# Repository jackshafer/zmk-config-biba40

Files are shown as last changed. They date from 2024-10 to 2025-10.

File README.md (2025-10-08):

# Biba40
## The BIBA40 is a compact, split, wireless keyboard powered by ZMK firmware and two microcontrollers.

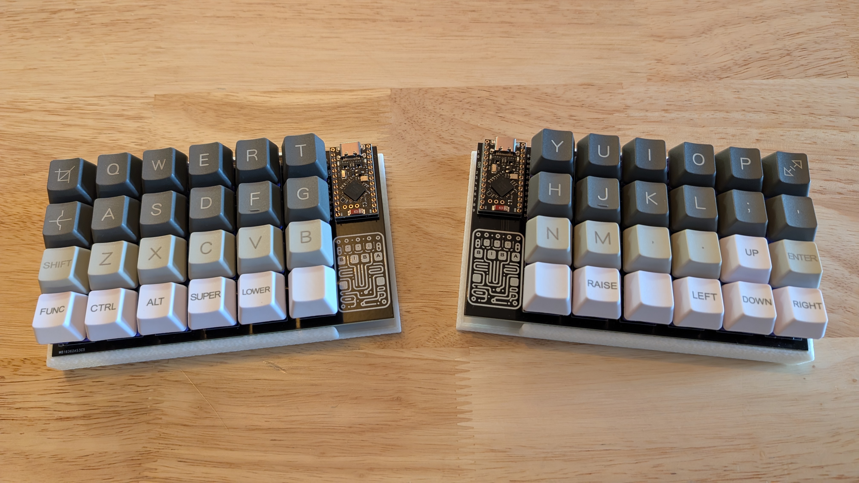
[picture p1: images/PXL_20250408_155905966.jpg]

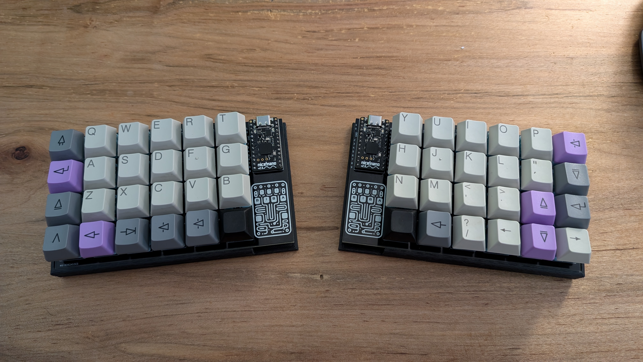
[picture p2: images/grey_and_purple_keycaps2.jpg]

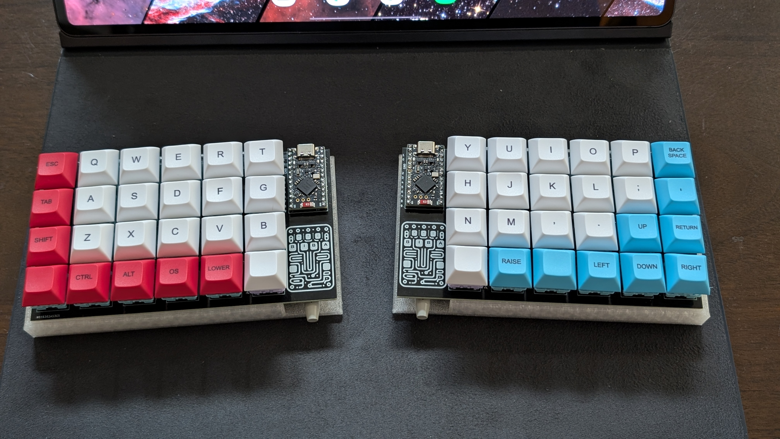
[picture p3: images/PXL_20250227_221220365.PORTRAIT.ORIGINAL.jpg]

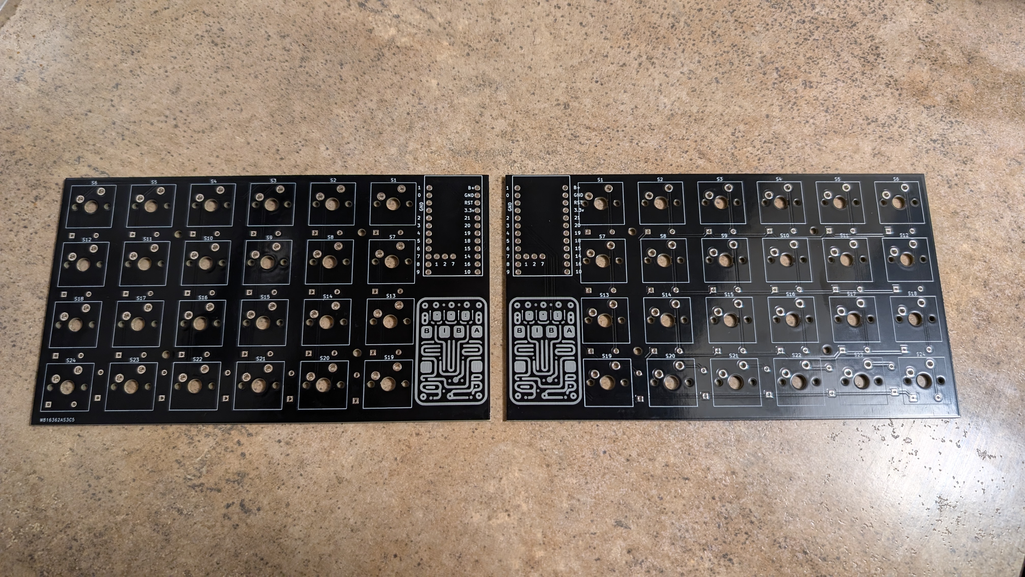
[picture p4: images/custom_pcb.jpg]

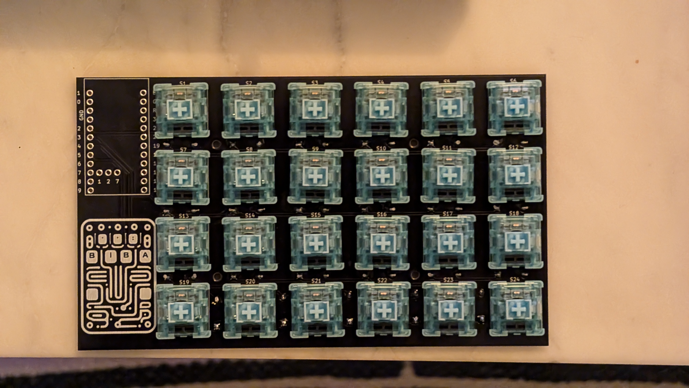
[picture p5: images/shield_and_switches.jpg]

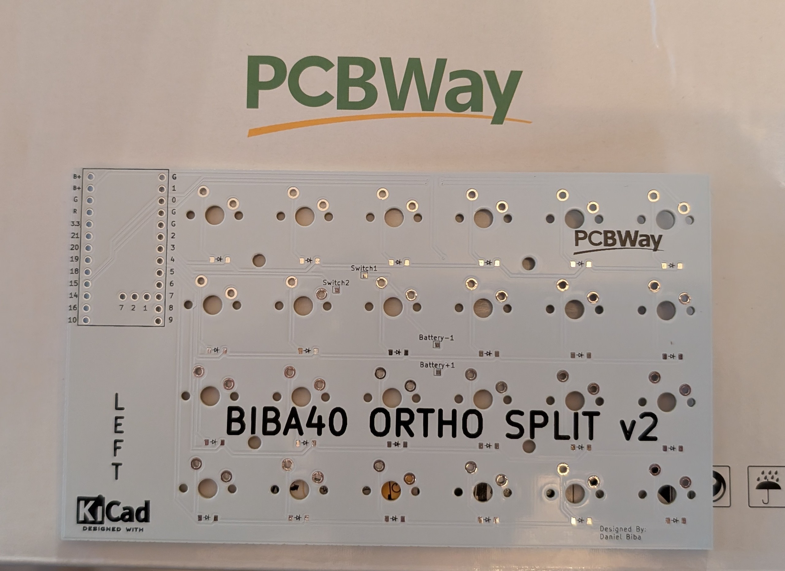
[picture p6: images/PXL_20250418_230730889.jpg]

A 40% Split Ortholiner wireless keyboard powered by ZMK.

* Keyboard Maintainer: [Daniel Biba](https://github.com/danbiba)
* Hardware Supported: nice!nano v2, Supermini NRF52840
* Hardware Availability: 3D Printable
* Buy your own : https://bibakeyboards.com/

## Keymap
### Default Layer
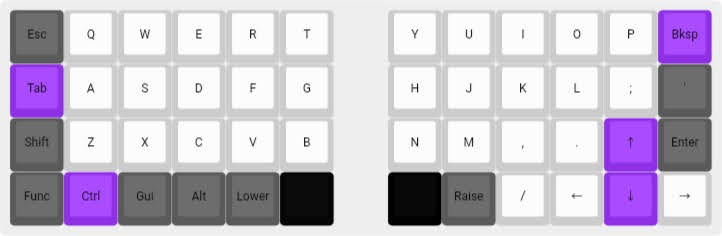
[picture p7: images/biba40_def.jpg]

### Lower Layer
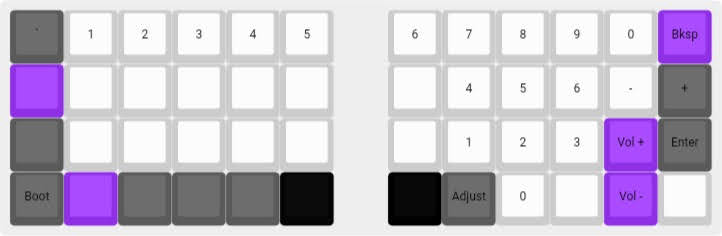
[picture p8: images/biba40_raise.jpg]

### Raise Layer
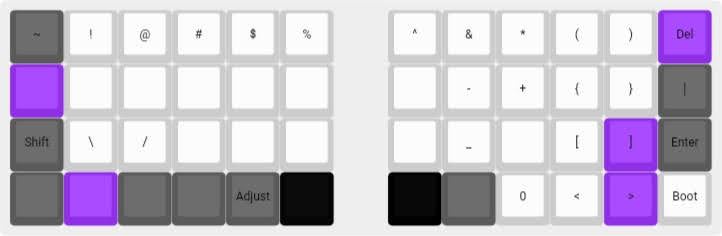
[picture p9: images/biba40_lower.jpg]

### Adjust Layer
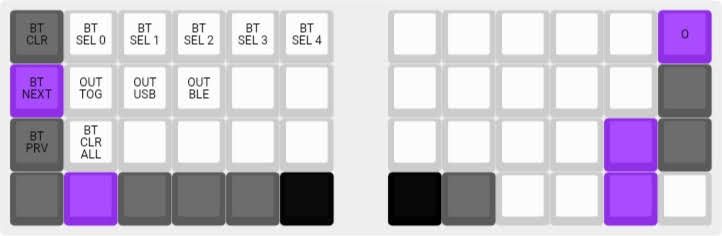
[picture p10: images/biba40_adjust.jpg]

### Function Layer
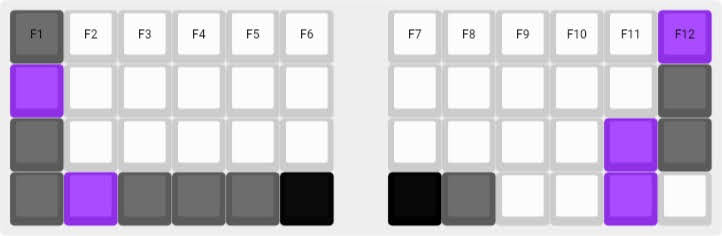
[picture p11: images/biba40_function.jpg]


## Setup
Clone the repository located at https://github.com/danbiba/zmk-config-biba40

Compile the firmware using Github actions. This will produce 3 files:

* biba40_left-nice_nano_v2-zmk.uf2
* biba40_right-nice_nano_v2-zmk.uf2
* settings_reset-nice_nano_v2-zmk.uf2

## Bootloader

Enter the bootloader in 3 ways:

* Lower + 0,3 (for the left board)
* Raise + 5,3 (for the right board)
* Short out pins RST and GND on the nice!nano v2

[View the BIBA40 V2 Build Guide](Build_Guide.md)

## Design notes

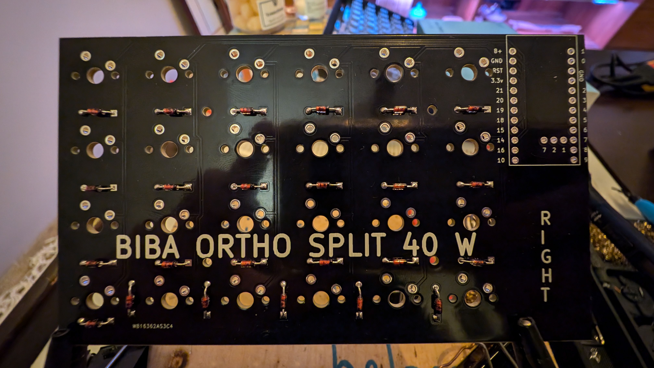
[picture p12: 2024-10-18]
images/shield_diodes.jpg

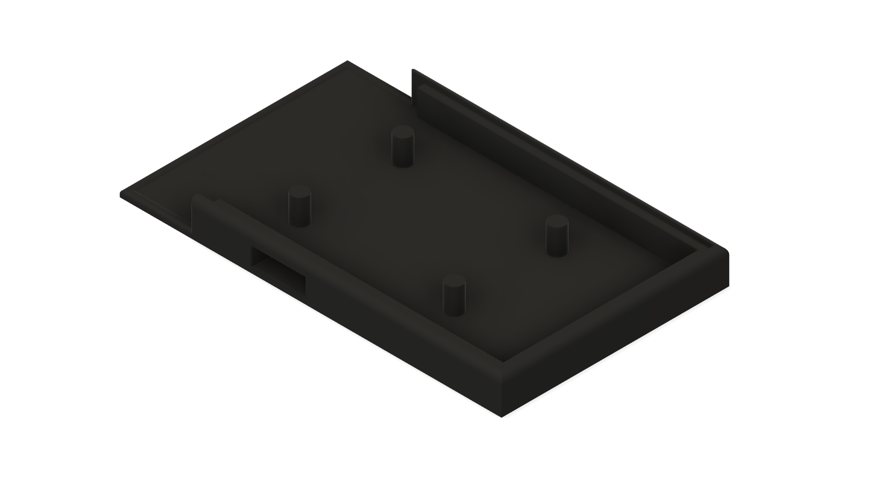
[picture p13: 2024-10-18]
images/split_40_case_rev2.png

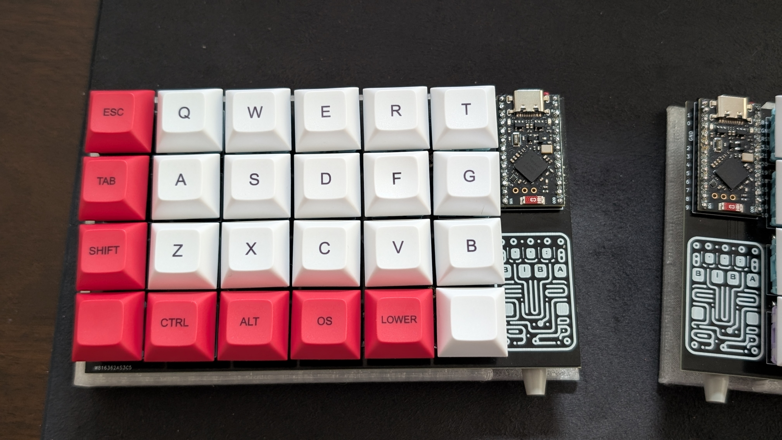
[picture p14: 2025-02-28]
images/PXL_20250227_221210475.PORTRAIT.ORIGINAL.jpg

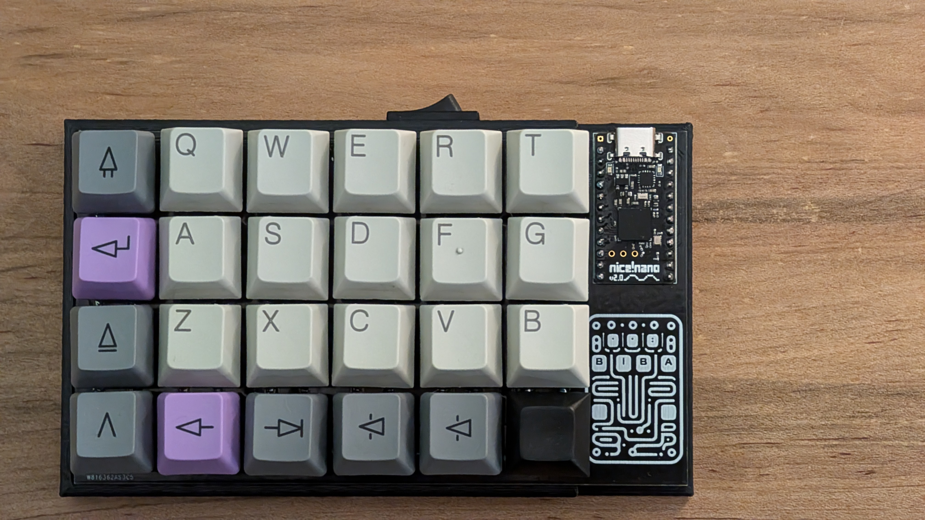
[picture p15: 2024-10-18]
images/left_side.jpg

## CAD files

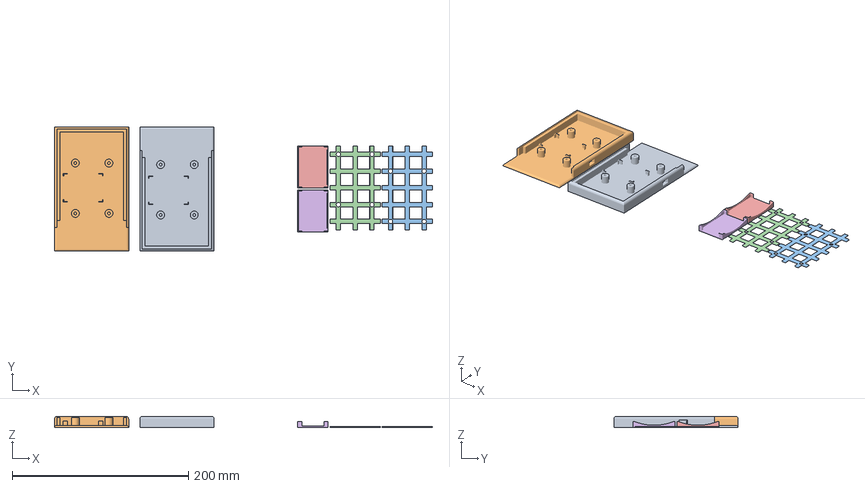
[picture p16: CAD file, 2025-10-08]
case/Biba40 Case Kit Sliced.3mf
428.9 x 141.2 x 13.0 mm
Case.stl x 2
Biba40 Alignment Plate v1.stl x 2
Battery Cover v2.stl x 2

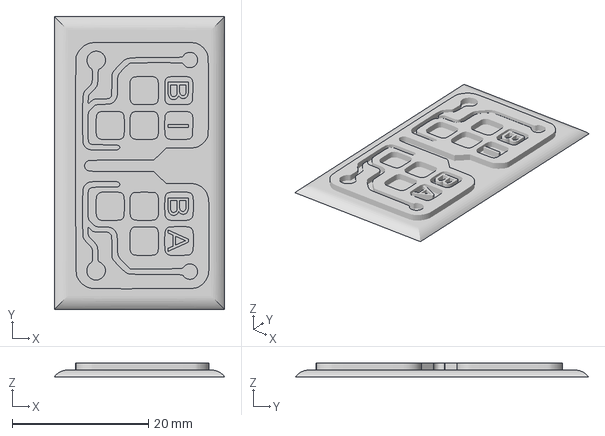
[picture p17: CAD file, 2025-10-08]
case/Biba Name Plate.3mf
25.0 x 43.0 x 2.00 mm

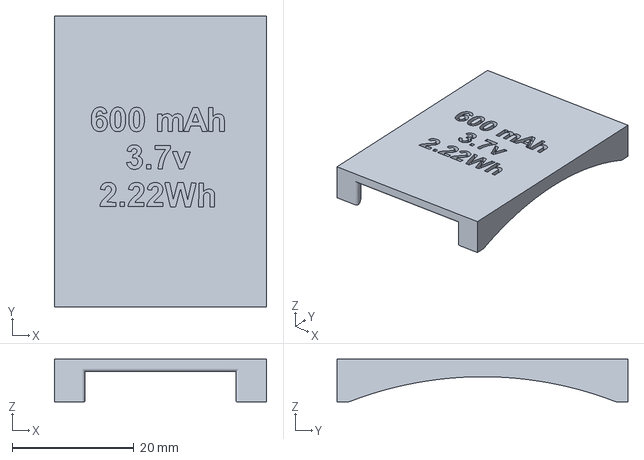
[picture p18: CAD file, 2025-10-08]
case/Biba40 Battery Cover v2.3mf
34.9 x 47.9 x 7.00 mm

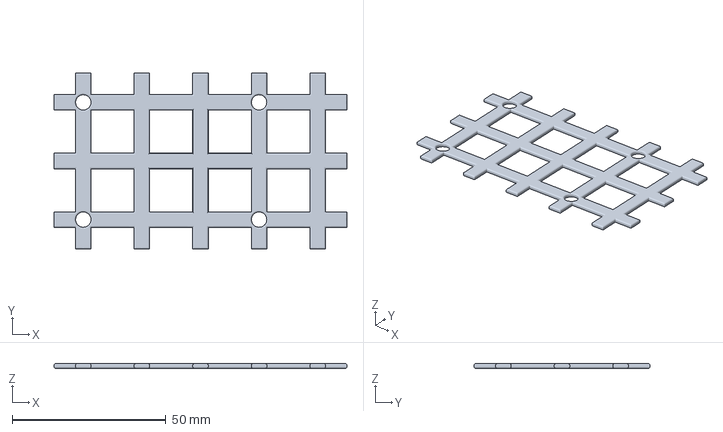
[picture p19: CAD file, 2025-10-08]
case/Biba40 Alignment Plate v1.3mf
95.2 x 57.1 x 1.50 mm

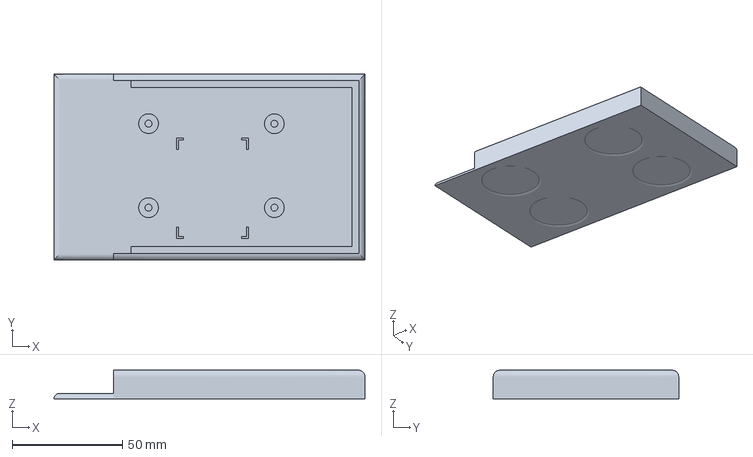
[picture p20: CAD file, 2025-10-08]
case/Biba40 Case v2.3mf
141.2 x 84.2 x 13.0 mm

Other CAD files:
case/Biba Name Plate.stl
case/Biba40 Alignment Plate v1.stl
case/Biba40 Battery Cover v2.stl
case/Biba40 Case v2.stl

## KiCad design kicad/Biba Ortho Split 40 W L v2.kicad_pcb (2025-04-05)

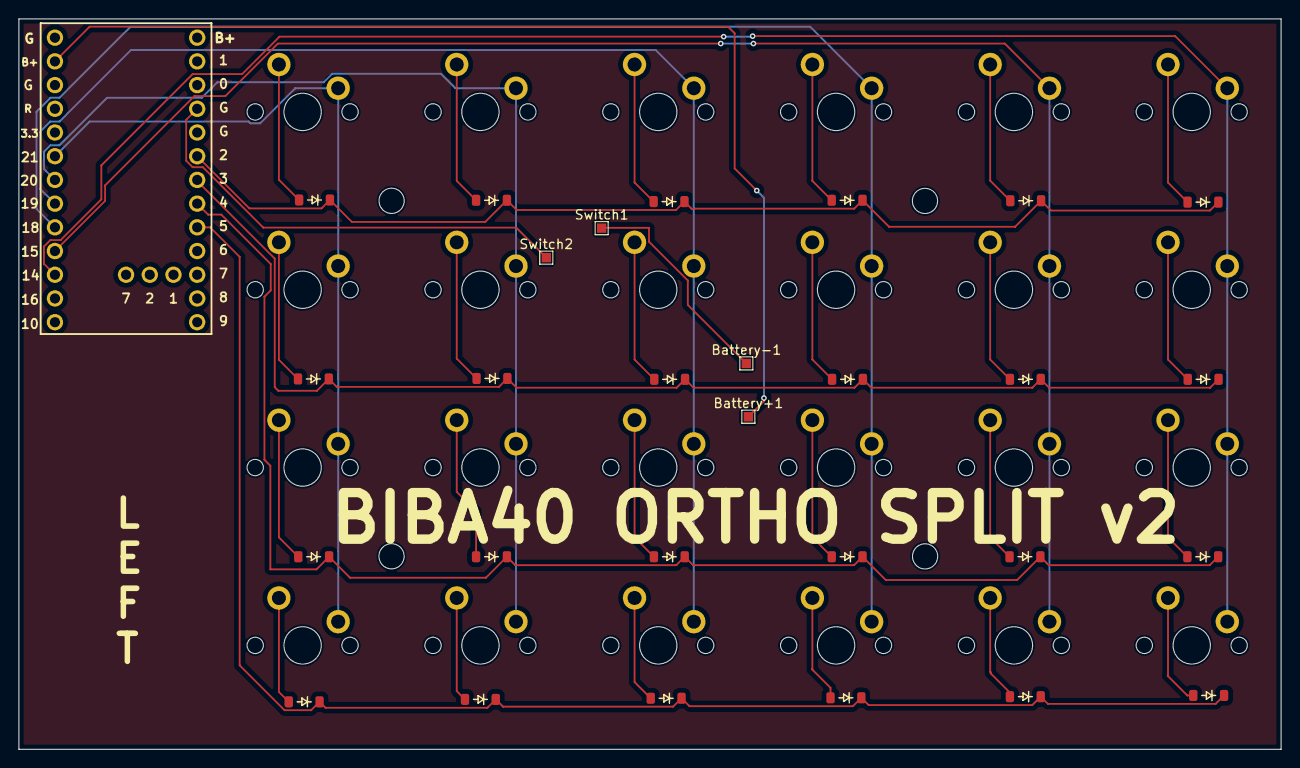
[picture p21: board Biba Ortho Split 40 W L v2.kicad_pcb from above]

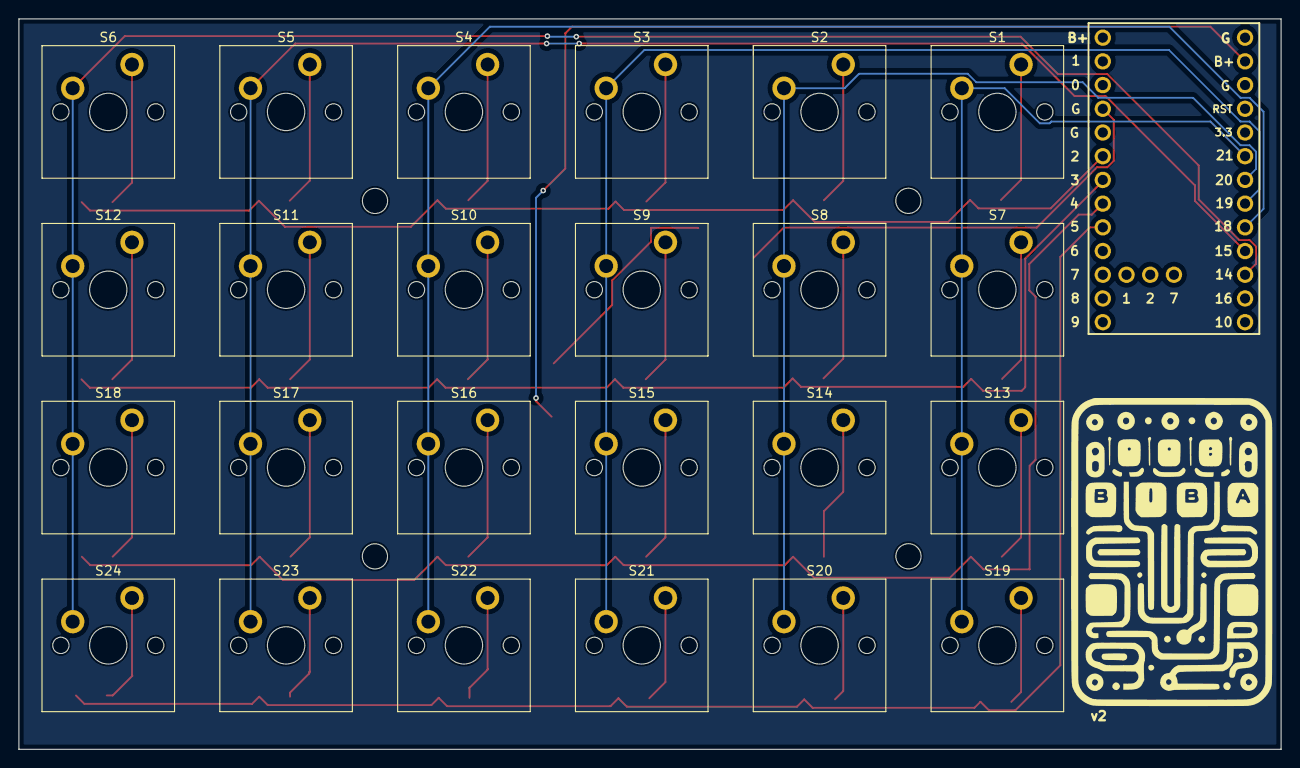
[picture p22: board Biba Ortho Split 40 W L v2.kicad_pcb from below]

Board: 2 copper layers, 135.2 x 78.2 mm, 53 parts (25 on the bottom side), 37 nets.

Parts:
Battery+1: Battery +; TestPoint_Pad_1.0x1.0mm
Battery-1: Battery -; TestPoint_Pad_1.0x1.0mm
D1, D2, D3, D4, D5, D6, D7, D8, D9, D10, D11, D12, D13, D14, D15, D16, D17, D18, D19, D20, D21, D22, D23, D24: Diode; Diode_SOD-123
S1, S2, S3, S4, S5, S6, S7, S8, S9, S10, S11, S12, S13, S14, S15, S16, S17, S18, S19, S20, S21, S22, S23, S24: Keyswitch; MX_PCB_1.00u
Switch1: Switch 1; TestPoint_Pad_1.0x1.0mm
Switch2: Switch 2; TestPoint_Pad_1.0x1.0mm
U1: SuperMini NRF52840

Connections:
Battery +: Battery+1.1, U1.24 (B+)
Battery -: Battery-1.1, Switch1.1
Column 0: S1.1, S7.1, S13.1, S19.1, U1.20 (21)
Column 1: S2.1, S8.1, S14.1, S20.1, U1.19 (20)
Column 2: S3.1, S9.1, S15.1, S21.1, U1.18 (19)
Column 3: S4.1, S10.1, S16.1, S22.1, U1.17 (18)
Column 4: S5.1, S11.1, S17.1, S23.1, U1.16 (15)
Column 5: S6.1, S12.1, S18.1, S24.1, U1.15 (14)
unnamed: D1.2 (A), S1.2
unnamed: D2.2 (A), S2.2
unnamed: D3.2 (A), S3.2
unnamed: D4.2 (A), S4.2
unnamed: D5.2 (A), S5.2
unnamed: D6.2 (A), S6.2
unnamed: D7.2 (A), S7.2
unnamed: D8.2 (A), S8.2
unnamed: D9.2 (A), S9.2
unnamed: D10.2 (A), S10.2
unnamed: D11.2 (A), S11.2
unnamed: D12.2 (A), S12.2
unnamed: D13.2 (A), S13.2
unnamed: D14.2 (A), S14.2
unnamed: D15.2 (A), S15.2
unnamed: D16.2 (A), S16.2
unnamed: D17.2 (A), S17.2
unnamed: D18.2 (A), S18.2
unnamed: D19.2 (A), S19.2
unnamed: D20.2 (A), S20.2
unnamed: D21.2 (A), S21.2
unnamed: D22.2 (A), S22.2
unnamed: D23.2 (A), S23.2
unnamed: D24.2 (A), S24.2
Row 0: D1.1 (K), D2.1 (K), D3.1 (K), D4.1 (K), D5.1 (K), D6.1 (K), U1.5 (2)
Row 1: D7.1 (K), D8.1 (K), D9.1 (K), D10.1 (K), D11.1 (K), D12.1 (K), U1.6 (3)
Row 2: D13.1 (K), D14.1 (K), D15.1 (K), D16.1 (K), D17.1 (K), D18.1 (K), U1.7 (4)
Row 3: D19.1 (K), D20.1 (K), D21.1 (K), D22.1 (K), D23.1 (K), D24.1 (K), U1.8 (5)
Switch1: Switch2.1, U1.3 (GND)

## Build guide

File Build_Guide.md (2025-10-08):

# BIBA40 Build Guide

> **Official Assembly Instructions for the BIBA40 Keyboard**
> Repository: [https://github.com/danbiba/zmk-config-biba40](https://github.com/danbiba/zmk-config-biba40)

---

## Introduction

The **BIBA40** is a compact, split, wireless keyboard powered by ZMK firmware and two microcontrollers. This guide provides a clear, step-by-step process for building the latest V2 revision, including 3D printing, assembly, flashing, and pairing.

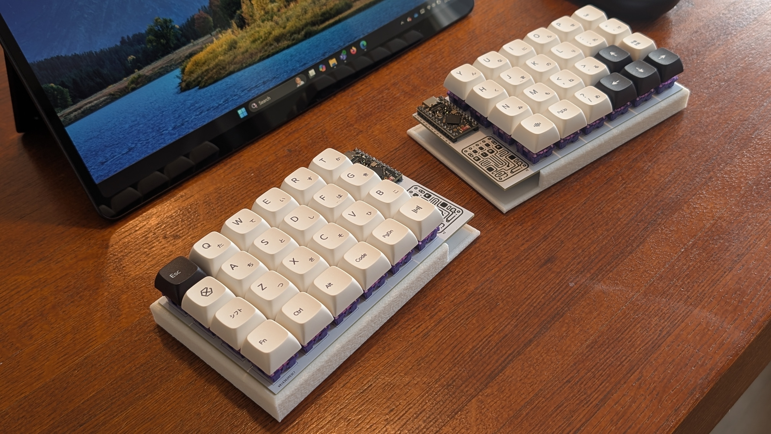
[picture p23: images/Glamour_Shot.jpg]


---

## PCB Fabrication

### Custom Printed PCB

If you're looking to have these PCBs custom made, use the Gerber files located in the **`kicad/Production`** folder to upload for manufacturing. The PCBs for the BIBA40 were produced by [PCBWay](https://www.pcbway.com/). Their fabrication process ensured a reliable build and helped bring this project to life. The **V2** boards were manufactured and delivered in under one week.



---

## Bill of Materials (BOM)

### Electronics

* 2 × BIBA40 **V2** PCBs (left and right) https://Bibakeyboards.com or order from PCBway
* 2 × Microcontrollers (e.g., **nice!nano v2** or **Supermini NRF52840**) with matching headers https://tinyurl.com/4uzn3k5p
* 48 × 1N4148W surface-mount diodes https://tinyurl.com/u4n7be6v
* 48 × Mechanical switches (5-pin recommended)
* 2 × 3.7V 600mAh LiPo batteries with JST-PH 2-pin connectors (one per half) https://tinyurl.com/yckcn2nw
* 2 × JST PH-2 to bare wire cables (battery to PCB connection) https://tinyurl.com/3m6w2ezd
* 2 × Power slide switches (one per half)
* Hook-up wire for power switch leads (approximately 4" per half)

### Case and Hardware

* 3D-printed components:

  * **Case ×2** (mirror one for left/right)
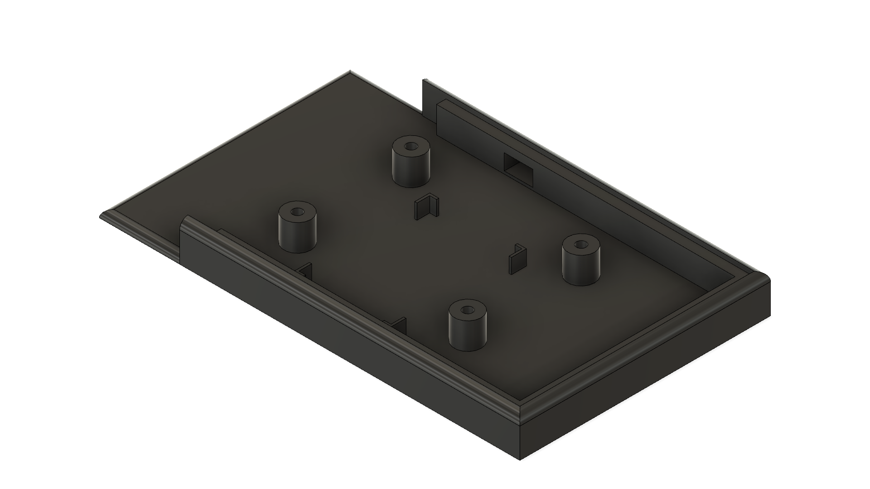
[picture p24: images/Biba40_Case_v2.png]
       
  * **Battery Cover ×2**
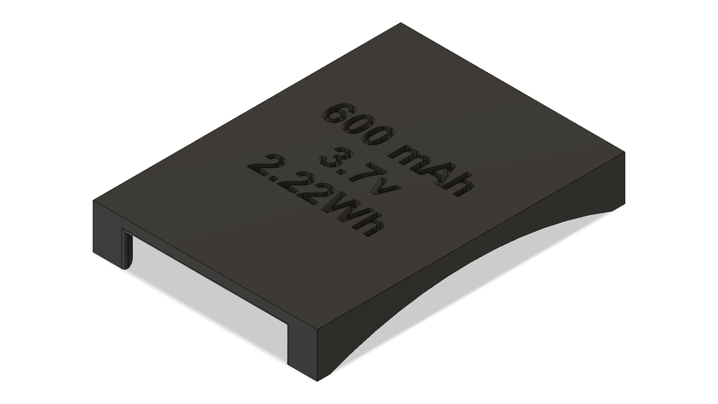
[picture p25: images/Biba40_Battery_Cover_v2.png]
    
  * **Mini Plate ×2**
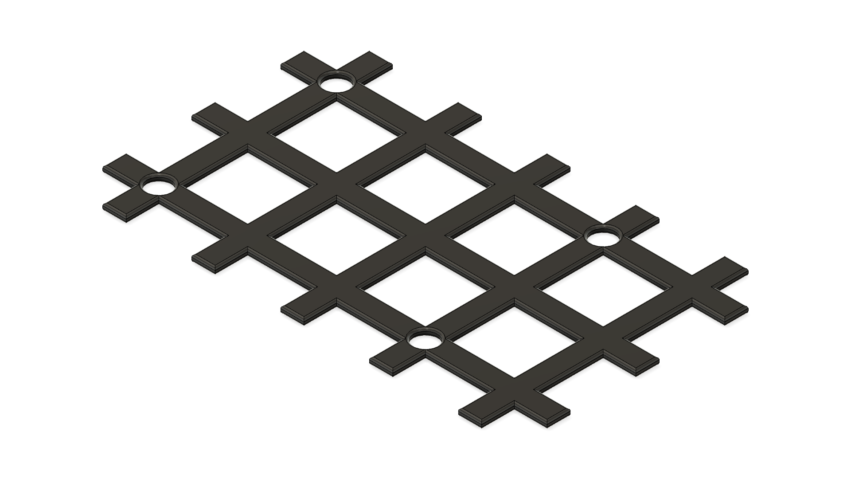
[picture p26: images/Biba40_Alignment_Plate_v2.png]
    
* Heat-set threaded inserts: **2-56 × 4.0** https://tinyurl.com/3tsjmrzd
* Machine screws (2-56 to match inserts) https://tinyurl.com/4tx2c6br
* Rubber adhesive feet https://tinyurl.com/4bz7kvkp
* Kapton or heat tape for wire strain relief https://tinyurl.com/54bem9f9

### Tools

* Soldering iron with fine tip, solder, and flux
* Hot-air rework station (optional) or iron reflow for SMD diodes
* Heat-set insert tool or temperature-controlled iron
* Tweezers
* Side cutters
* Precision screwdriver
* Multimeter for continuity checks
* 3D printer and filament

> **Safety Note:** Always disconnect batteries during soldering. Follow LiPo safety procedures and use ESD-safe handling for all electronics.

---

## Step 1: 3D Print the Case

1. Choose a filament color.
2. Slice and print the following:

   * Case ×2 *(mirror one if printing separately)*
   * Battery Cover ×2
   * Mini Plate ×2
3. If using a **pre-sliced file**, insert the power switch **during the print** when prompted by your printer. Ensure it fits and moves smoothly.

> **Tip:** Print a small calibration part first to confirm switch tolerances before committing to the full print.

---

## Step 2: Prepare and Assemble the Case

1. Heat-press **2-56 × 4.0** threaded inserts into the mounting slots.
   
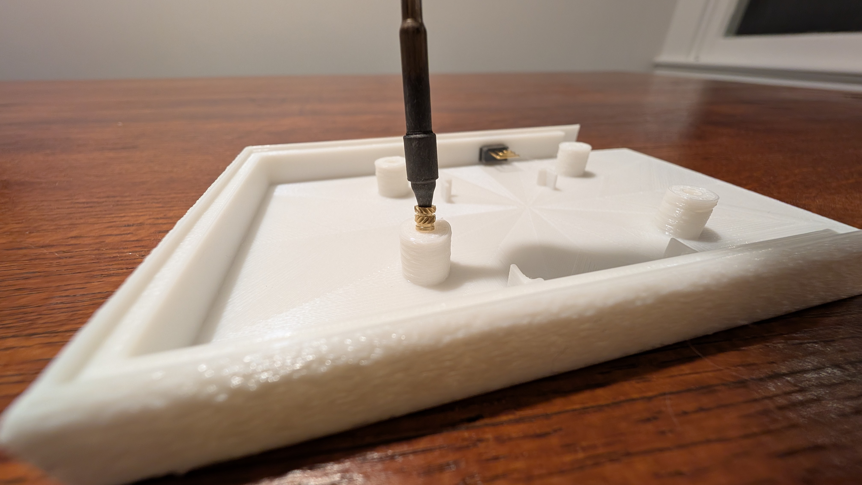
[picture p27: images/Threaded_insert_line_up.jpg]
   
   
3. Verify that each insert is aligned **perfectly vertical (90°)** relative to the side walls.

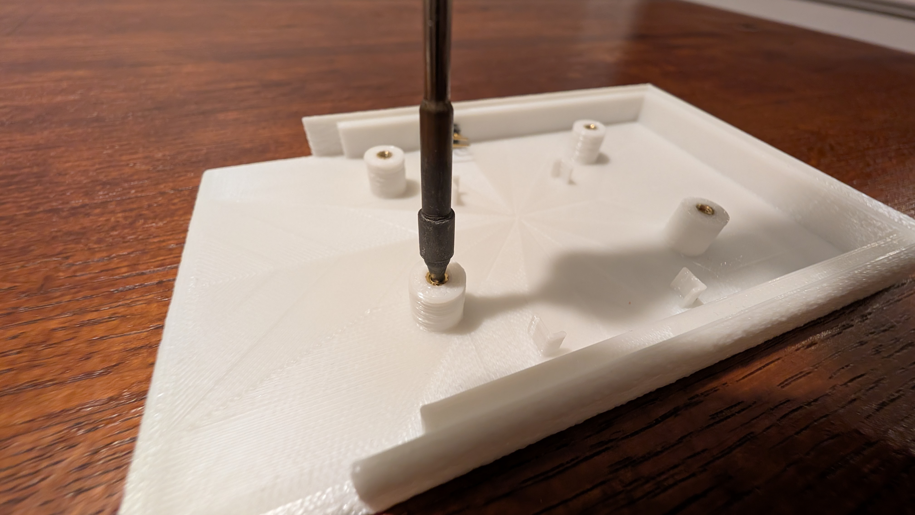
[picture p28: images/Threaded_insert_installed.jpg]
   
   
5. Apply **rubberized feet** to the bottom of each case.

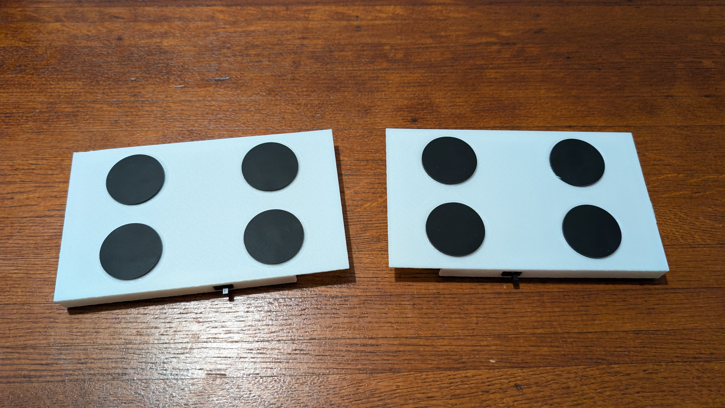
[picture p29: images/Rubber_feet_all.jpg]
   

7. Straighten **power switch leads**, if necessary.
8. Secure the switch using a soldering iron or a **small dab of super glue**.
9. Solder two **4-inch wires** to the switch, leaving bare ends for the PCB connection.
10. Insert the **battery** into its slot, route cables upward, and attach the **battery cover**.
    
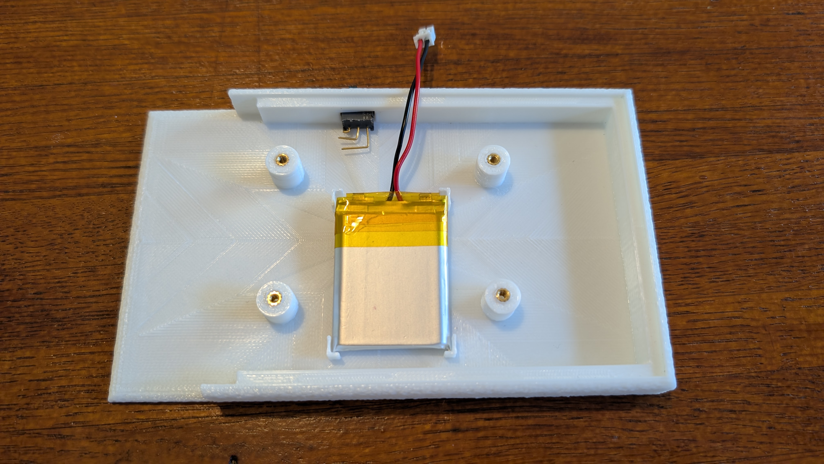
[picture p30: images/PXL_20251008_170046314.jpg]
    
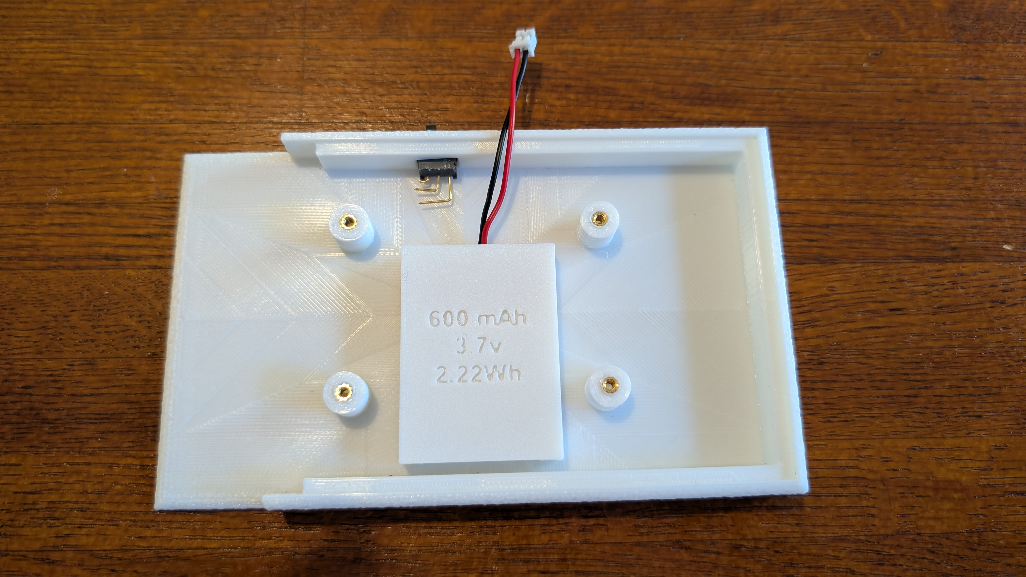
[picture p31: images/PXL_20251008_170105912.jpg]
    

---

## Step 3: Flash the Microcontrollers

1. Connect one microcontroller via USB.
2. If the computer does not detect it, short **RST** and **GND** twice to enter bootloader mode.
3. Drag the correct **ZMK firmware UF2** file (left or right) onto the mounted drive. The device will automatically disconnect when flashing completes.
4. Label the microcontroller **Left** or **Right**.
5. Repeat for the second half.

---

## Step 4: Assemble the PCB

1. **Pre-tin** one pad of each diode footprint.
2. **Pre-tin** both battery and switch pads.
3. Align each diode with correct **polarity** and reflow the pre-tinned pad. Hold until secure.
4. Repeat for all **48 diodes**.
5. Solder the second pad of each diode and inspect for cold joints or solder bridges.
6. Reflow as needed.
7. Solder the **battery connector cable** to the battery pads (**red = +**, **black = −**).
8. Use Kapton tape to secure the cable, routing it **away from the microcontroller**.
9. Fit the **headers** using the microcontroller as a spacer. Tack-solder one or two pins on each side.
10. Remove the microcontroller and complete header soldering.
11. Reinstall and solder the microcontroller carefully.
12. Insert switches into the **mini plate** to confirm alignment; some edge switches may require manual support.
13. Flip the board and solder the switch pins, ensuring switches sit **flush** to the PCB.
14. Add and solder any remaining switches.

---

## Step 5: Final Assembly

1. Match each PCB with its corresponding case and place it **face down**.
2. Solder the **switch wires** to the two **Switch** pads on the bottom of the PCB.
3. Connect the **battery** to the PCB’s battery plug.
4. Use Kapton tape to organize wires, avoiding excessive strain.
5. Flip the PCB into position, aligning the screw holes.
6. Insert screws through the **mini plate** and into the **threaded inserts**. Tighten gently.
7. Install **keycaps**.

---

## Step 6: Power Up and Pairing

1. Turn on the **left half**.
2. Turn on the **right half**. The halves will automatically pair.
3. On your device, connect to the Bluetooth keyboard named **“BIBA40.”**

> If pairing fails, power-cycle both halves and retry. Only power one left and one right half during initial pairing.

---

## Troubleshooting

| Issue | Possible Cause | Solution |
| --- | --- | --- |
| **Microcontroller not detected** | Not in bootloader mode | Short **RST** to **GND** twice and retry. |
| **Keys not responding** | Incorrect diode orientation or cold joint | Verify polarity, reflow joints. |
| **No power on one half** | Incorrect battery polarity or wiring | Check connections and switch orientation. |
| **Bluetooth pairing issues** | Cached pairing data | Remove device from Bluetooth settings and re-pair. |

> For advanced troubleshooting, refer to the [ZMK documentation](https://zmk.dev/docs/).

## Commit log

2025-08-11 Update west.yml
    Pin ZMK version to v0.2
2025-10-01 Fix Esc key
2025-10-08 Rename Biba40 Case v2 v19.png to Biba40_Case_v2.png
2025-10-08 Rename Biba40 Battery Cover v2 v19.png to Biba40_Battery_Cover_v2.png
2025-10-08 Rename Biba40 Alignment Plate v2.png to Biba40_Alignment_Plate_v2.png
2025-10-08 Rename Biba40 Case rev 3.3mf to Biba40 Case Kit Sliced.3mf
    [Biba40 Case Kit Sliced.3mf]
2025-10-10 Delete boards/shields/biba40/biba40.keymap
    File cleanup
2025-10-10 Update biba40.keymap
    build(studio): enable Studio on left via snippet and CONFIG_ZMK_STUDIO
    ci: use ZMK build-user-config workflow @main
    west: track ZMK main for Studio testing
    keymap: add &studio_unlock on FUNCTION
2026-04-01 Change board name from nice_nano_v2 to nice_nano
2026-04-01 Update board references to include '//zmk' suffix
2026-09-18 Enable sleep mode in ZMK configuration
    Add power management configuration for ZMK.
